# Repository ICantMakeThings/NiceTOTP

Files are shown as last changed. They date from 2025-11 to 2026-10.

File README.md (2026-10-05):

# NiceTOTP certification-mark-PL000020-wide

ew
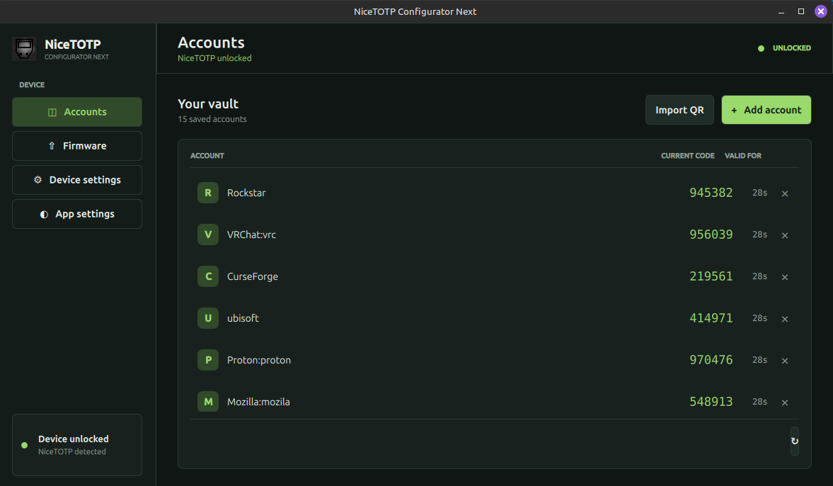
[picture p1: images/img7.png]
Repeat new PIN


## Wiki

- [What is NiceTOTP?](#what-is-nicetotp)
- [But Why?](#but-why)
- [Hardware](#hardware-is)
- [Usage](#usage)
	- [UI](Docs/ui.md)
- [Installation](#installation)
	- [Standard installation](#standard-installation)
	- [Protected installation](#protected-installation)
- [More Info](#more-info)
- [Build protected from source](Docs/build-protected-from-source.md)

# What is NiceTOTP?

Time-based one-time password (TOTP). aka: 2FA! 
A alternetive to [Authy](https://www.authy.com/) / [Google Authenticator](https://play.google.com/store/apps/details?id=com.google.android.apps.authenticator2). 

Full offline, Air Gapped. And Standalone once all Keys have been added.

TOTP keys and other FS are stored in an AES-256-GCM encrypted vault, with a key derived from the passcode using PBKDF2-HMAC-SHA-256. Vaults use a random starting IV followed by monotonically increasing IVs.

A four-digit passcode is still vulnerable to offline guessing if an attacker extracts the flash. Use a longer, unpredictable numeric passcode; a lengt of 13 can make a attacker wait up to 8 years on the most common GPU* 

[Video here](https://www.youtube.com/watch?v=sLiadPXk7rc)

## But Why?? 

There are a few reasons why I made this device, mainly to lose dependence of my phone. But not just, What if your phone breaks, bricks, or something else? I rather have lots of devices that don't depend on eachother rather than a all in one for that reason, plus most "universal" stuff performs worse than a specific device for that single function. As of right now, I'd say it's almost complete (enough to daily drive), possibly a few more hardware security features, maybe UI polishing, fixing any bugs i haven't found yet and should be perfect. The cost is ~£6 excluding 3D printing.

## Hardware is:
+ Nice!Nano: [AliExpress Link](https://s.click.aliexpress.com/e/_omlmCuu)
+ DS3231 RTC: [AliExpress Link](https://s.click.aliexpress.com/e/_omVV4ia)
+ 0.96Inch Display: [AliExpress Link](https://s.click.aliexpress.com/e/_ooXwYgq)
+ 6*6 Silicone Switch: [AliExpress Link](https://s.click.aliexpress.com/e/_oDcs8Wa)
+ 3D [model](https://www.thingiverse.com/thing:7087241)

*Note: These are referral links. If you purchase through it, I earn a commission at no extra cost to you.*

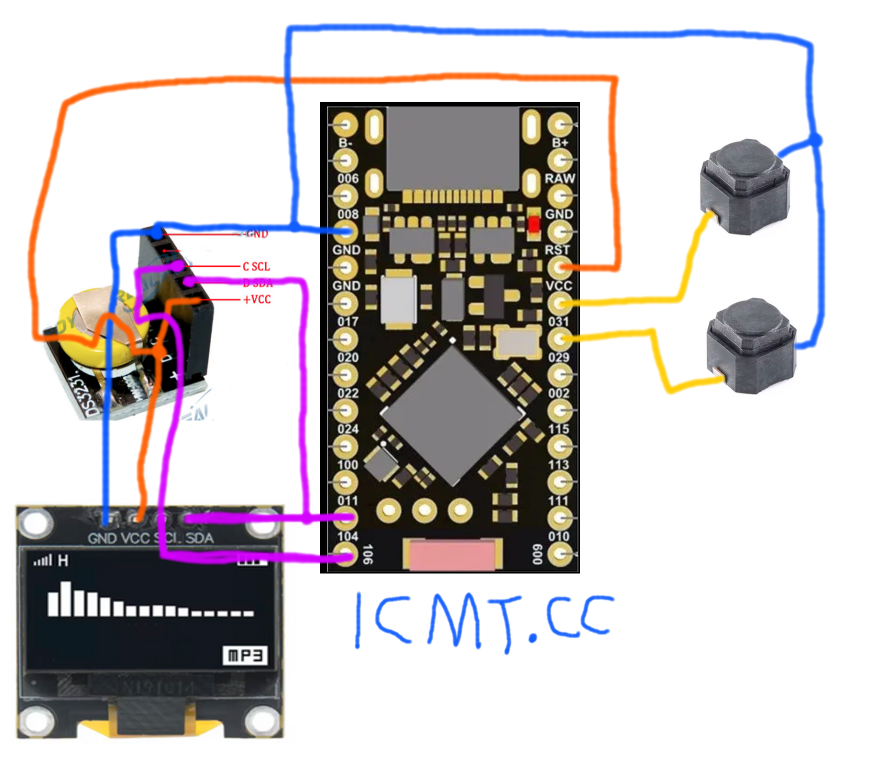
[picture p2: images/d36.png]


# Usage
#### Use the [NiceTOTP-ConfiguratorNext](https://github.com/ICantMakeThings/NiceTOTP/releases)  (Firmware update doesnt work rn*)
#### or you can use serial commands:
- `setunixtime` example: `setunixtime 1751925355` 
- The first `setunixtime` stores the real time for future auto-calibration which after 30 days it will compensate for any drift in the DS3231.
- `manualcalibration <offset>` example: `manualcalibration 3` sets the DS3231 aging register from -128 to 127 and locks automatic calibration
- `lockcalibration` stops auto-calibration
- `unlockcalibration` turns back on auto-calibration
- `getcalibration` reports the aging offset, baseline timestamp, and lock state
- `clearcalibration` clears the aging correction and removes the stored calibration baseline
- `add <username> <base32secret>` example: `add test JBSWY3DPEHPK3PXP` ([Compare](https://totp.danhersam.com/?secret=JBSWY3DPEHPK3PXP))
- `list`
- `del <GetTheIDFromListCommand>` example: `del 1`
- `factoryreset` (Power cycle after)

# Installation

### Standard installation

If you don't care about proper security*, download the [NiceTOTP-ConfiguratorNext](https://github.com/ICantMakeThings/NiceTOTP/releases) and use the unsigned `NiceTOTP-V1x.uf2` firmware.

**Or if you just want to test the device without commiting to the protected bootloader / hassle with setting it up or not owning a ST-Link*

+ Or Drag and drop the .UF2 onto the nicenano drive when doubble clicking reset (short rst pin with usbc sheild tapping twice quickly)

### Protected installation
- Download `Signed.zip` from latest release, and follow
[Protected installation](Docs/build-protected-from-source.md) (Also includes installing from source)

# More Info

+ In 2 months the RTC drifted 8s forward. (Now there is a calibration feature, so should be better, to be commented on further.)

+ Battery seems to last about 1 year with a 1000mAh Battery.

+ Make sure not to let it discharge as it will go in a soft brick, to unbrick you just press rst 

#### GPU* 

- The algorythm is **50,000 PBKDF2** and the number is the expected value which is ½ of the worse-case scenario.
- It is based on cracking it with a NVIDIA GeForce RTX 3060 as its the most common GPU based on [Steam Hardware & Software Survey: August 2026.](https://store.steampowered.com/hwsurvey/En)
- It is recommended to have a pin of at least 13 Charicters
- You can have a look on [this webiste](https://jmrp.io/tools/pin-brute-force-calculator/) to test around different hardware, make sure PBKDF2 iterations is set to `50000`

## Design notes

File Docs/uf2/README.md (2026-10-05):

# USB Flashing Format (UF2)

UF2 is a file format, developed by Microsoft for [PXT](https://github.com/Microsoft/pxt) 
(also known as [Microsoft MakeCode](https://makecode.com)), that is particularly suitable for 
flashing microcontrollers over MSC (Mass Storage Class; aka removable flash drive).

For a more friendly explanation, check out [this blog post](https://makecode.com/blog/one-chip-to-flash-them-all).
Also, take a look at the list of [implementations](#implementations) at the bottom of this document.

## Overview

The UF2 file consists of 512 byte blocks, each of which is self-contained and independent of others. 
Each 512 byte block consists of (see below for details):
* magic numbers at the beginning and at the end
* address where the data should be flashed
* up to 476 bytes of data

The data transfers over MSC always arrive in multiples of 512 bytes.
Together with the FAT file system structure, this means that blocks of the
UF2 file are always aligned with the MSC writes - the microcontroller 
never gets a partial file.

The magic numbers let the microcontroller distinguish an UF2 file block from
other data (eg., FAT table entry, or various book-keeping files stored by some
operating systems).  When a UF2 block is recognized, it can be flashed
immediately (unless flash page size is more than 256 bytes; in that case a buffer
is needed). The actual handling of file format during writing is very simple
(~10 lines of C code in simplest version).

## File format

A UF2 file consists of 512 byte blocks. Each block starts with a 32 byte
header, followed by data, and a final magic number.
All fields, except for data, are 32 bit unsigned little endian integers.

| Offset | Size | Value |
|---|---|---|
| 0 | 4 | First magic number, `0x0A324655` (`"UF2\n"`) |
| 4 | 4 | Second magic number, `0x9E5D5157` |
| 8 | 4 | Flags |
| 12 | 4 | Address in flash where the data should be written |
| 16 | 4 | Number of bytes used in data (often 256) |
| 20 | 4 | Sequential block number; starts at 0 |
| 24 | 4 | Total number of blocks in file |
| 28 | 4 | File size or board family ID or zero |
| 32 | 476  | Data, padded with zeros |
| 508 | 4 | Final magic number, `0x0AB16F30` |

The following C struct can be used:

```C
struct UF2_Block {
    // 32 byte header
    uint32_t magicStart0;
    uint32_t magicStart1;
    uint32_t flags;
    uint32_t targetAddr;
    uint32_t payloadSize;
    uint32_t blockNo;
    uint32_t numBlocks;
    uint32_t fileSize; // or familyID;
    uint8_t data[476];
    uint32_t magicEnd;
} UF2_Block;
```

### Flags

Currently, there are five flags defined:

* `0x00000001` - **not main flash** - this block should be skipped when writing the
  device flash; it can be used to store "comments" in the file, typically
  embedded source code or debug info that does not fit on the device flash
* `0x00001000` - **file container** - see below
* `0x00002000` - **familyID present** - when set, the `fileSize/familyID` holds a value
  identifying the board family (usually corresponds to an MCU)
* `0x00004000` - **MD5 checksum present** - see below
* `0x00008000` - **extension tags present** - see below

### Family ID

This field is optional, and should be set only when the corresponding
flag is set. It is recommended that new bootloaders require the field to
be set appropriately, and refuse to flash UF2 files without it.
If you're developing your own bootloader, and your
board family isn't listed here, pick a new family ID at random. It's good
to also send a PR here, so your family can be listed.

If the `familyID` doesn't match, the bootloader should disregard the
entire block, including `blockNo` and `numBlocks` fields.
In particular, writing a full UF2 file with non-matching `familyID`
should not reset the board.
This also allows for several files with different `familyID` to be
simply concatenated together, and the whole resulting file to be copied
to the device with only one actually being written to flash.

#### Picking numbers at random

The reason to pick numbers at random is to minimize risk of collisions
in the wild. Do not pick random numbers by banging on keyboard, or by using
`0xdeadf00d`, `0x42424242` etc. A good way is to use the following
shell command: `printf "0x%04x%04x\n" $RANDOM $RANDOM`
Another good way is the link at the bottom of https://microsoft.github.io/uf2/patcher/
This procedure was unfortunately not used for the SAMD51 and NRF52840 below.

#### Family list

The current master list of family IDs is maintained in a [JSON file](../../uf2/utils/uf2families.json).

### Rationale

The magic number at the end is meant to mitigate partial block writes.

Second and final magic numbers were randomly selected, except for the last byte
of final magic number, which was forced to be `'\n'` (`0xA`). Together with the
first magic number being `"UF2\n"` this makes it easy to identify UF2 blocks in
a text editor.

The header is padded to 32 bytes, as hex editors commonly use 16 or 32 bytes
as line length.  This way, the data payload is aligned to line start.

32 bit integers are used for all fields so that large flash sizes can be
supported in future, as well as for simplicity. Little endian is used, as most
microcontrollers are little endian. 8 bit microcontrollers can choose to just
use the first 16 bits of various header fields.

The total number of blocks in the file and the sequential block number make it
easy for the bootloader to detect that all blocks have been transferred. It
requires one bit of memory per block (eg., on SAMD21G18A it's 128 bytes).
Alternatively, the bootloader might ignore that and just implement a reset
after say 1 second break in incoming UF2 blocks.

### Payload sizes

The number of data bytes is configurable and depends on the size of
the flash page (that is the smallest size that can be erased) on the
microcontroller.

* if the page size is more than `476` bytes, the bootloader should support
  any payload size, as it needs to buffer the entire page in memory anyway
* if the page size is less than `476` bytes, the payload should be a multiple
  of page size, so it can be written without buffering; the target address
  should also be a multiple of page size

In any event, payload size and target address should always be 4-byte aligned.

Note that payload size of `256` is always correct, and makes it easy to convert
between flash addresses and UF2 file offsets.

For example, on Atmel's SAMD21 chips the page size is `256` bytes, and this 
also is the payload size. If the page size was `128` bytes, one could use
payload of `128*3`. Nordic nRF51 has page size of `1024` bytes, and thus 
any payload size should be allowed.

### Embedding sources

Some IDEs will embed program sources in the UF2 file. This allows a UF2 files to be
loaded by the IDE and serve as a natural backup and transfer format.
This can be done in two ways:

* using the "not main flash" flag
* using normal blocks that are flashed to the device

If the bootloader can expose `CURRENT.UF2` file (see below) and there is enough
flash available, than the second option is more desirable, as it allows sharing
programs directly from the board.

See https://makecode.com/source-embedding for more info.

### Robustness

The file format is designed specifically to deal with the following problems:

* operating system (OS) writing blocks in different order than occurs in a file
* OS writing blocks multiple times
* OS writing data that is not UF2 blocks
* OS writing first/final part of a block, possibly for metadata detection or search indexing

The only file system assumption we make is that blocks of file are aligned with
blocks on the hard drive. It's likely true of many file systems besides FAT.

We also assume that USB MSC device reports its block size to be a multiple of `512`
bytes. In the wild these devices always almost report exactly `512`, and some
operating systems do not support other values.

## Files exposed by bootloaders

Bootloaders may expose virtual files in their MSC devices.  These are
standardized here, so that flashing tools can automatically detect the
bootloaders.

* `INFO_UF2.TXT` - contains information about the bootloader build and the board on which it is running
* `INDEX.HTM` - redirects to a page that contains an IDE or other information
* `CURRENT.UF2` - the contents of the entire flash of the device, starting at `0x00000000`, with `256` payload size;
  thus, the size of this file will report as twice the size of flash

Flashing tools can use the presence of `INFO_UF2.TXT` (in upper or lower case,
as FAT is case-insensitive) file as an indication that a given directory is
actually a connected UF2 board. The other files should not be used for
detection.

Typical `INFO_UF2.TXT` file looks like this:
```
UF2 Bootloader v1.1.3 SFA
Model: Arduino Zero
Board-ID: SAMD21G18A-Zero-v0
```

The `Board-ID` field is machine-readable and consists of a number of dash-separated tokens.
The first token is the CPU type, second is the board type, and third is the board revision.
More tokens can be also added.

The bootloader should contain its info file as a static string somewhere in its code.
If possible, the last word of the bootloader code should point to this string.
This way, the info file can be found in the initial section of the `CURRENT.UF2`
file as well. Thus, a board type can be determined from the contents of `CURRENT.UF2`.
This is particularly useful with the source embedding (see above).

## File containers

It is also possible to use the UF2 format as a container for one or more
regular files (akin to a TAR file, or ZIP archive without compression).  This
is useful when the embedded device being flashed sports a file system.

The program to run may reside in one of the files, or in the main flash memory.

In such a usage the `file container` flag is set on blocks, the field `fileSize`
holds the file size of the current file, and the field `targetAddr` holds the
offset in current file.

The `not main flash` flag on blocks should be ignored when the `file container` is set.

The file name is stored at `&data[payloadSize]` (ie., right after the actual payload) and
terminated with a `0x00` byte.  The format of filename is dependent on the
bootloader (usually implemented as some sort of file system daemon). 

The bootloader will usually allow any size of the payload.

The current files on device might be exposed as multiple UF2 files, instead of
a single `CURRENT.UF2`. They may reside in directories, however, due to UF2 general
design, it doesn't matter which directory the UF2 file is written to.

Typical writing procedure is as follows:
* validate UF2 magic numbers
* make sure that `targetAddr < fileSize` and that `fileSize` isn't out of reasonable range
* write `0x00` at `data[475]` to ensure NUL termination of file name
* read file name from `&data[payloadSize]`; perform any mapping on the file name
* create a directory where the file is to be written if it doesn't exist
* open the file for writing
* truncate the file to `fileSize`
* seek `targetAddr`
* write the payload (ie., `data[0 ... payloadSize - 1]`)
* close the file

The fields `blockNo` and `numBlocks` refer to the entire UF2 file, not the current
file.

## MD5 checksum

When the `0x4000` flag is set, the last 24 bytes of `data[]` hold the following structure:

| Offset | Size | Value |
|---|---|---|
| 0 | 4 | Start address of region |
| 4 | 4 | Length of region in bytes |
| 8 | 16 | MD5 checksum in binary format |

The flashing program should compute the MD5 sum of the specified region.
If the region checksum matches, flashing of the current block can be skipped.
Typically, many blocks in sequence will have the same region specified,
and can all be skipped, if the matching succeeded.
The position of the current block will typically be inside of the region.
The position and size of the region should be multiple of page erase size
(4k or 64k on typical SPI flash).

This is currently only used on ESP32, which is also why MD5 checksum is used.

## Extension tags

When the `0x8000` flag is set, additional information can be appended right after
payload data (i.e., it starts at `32 + payloadSize`).
Every tag starts at 4 byte boundary.
The first byte of tag contains its total size in bytes (including the size byte
and type designation).
The next three bytes designate the type of tag (if you want to define custom
tags, pick them at random).
The last tag has size of `0` and type of `0`.

Standard tag designations follow:
* `0x9fc7bc` - version of firmware file - UTF8 semver string
* `0x650d9d` - description of device for which the firmware file is destined (UTF8)
* `0x0be9f7` - page size of target device (32 bit unsigned number)
* `0xb46db0` - SHA-2 checksum of firmware (can be of various size)
* `0xc8a729` - device type identifier - a refinement of `familyID` meant to identify a kind of device
  (eg., a toaster with specific pinout and heating unit), not only MCU; 32 or 64 bit number; can be hash of `0x650d9d`

For example, the following bytes encode firmware version `0.1.2` for device
named `ACME Toaster mk3` (line breaks added for clarity):

```
09 bc c7 9f 30 2e 31 2e 32 00 00 00
14 9d 0d 65 41 43 4d 45 20 54 6f 61 73 74 65 72 20 6d 6b 33
00 00 00 00
```

Extension tags can, but don't have to, be repeated in all blocks.

## Implementations

### Bootloaders

* [Microchip ATSAMD21 and ATSAMD51](https://github.com/Microsoft/uf2-samdx1)
* [Arduino UNO](https://github.com/mmoskal/uf2-uno)
* [STM32F103](https://github.com/mmoskal/uf2-stm32)
* [STM32F4](https://github.com/mmoskal/uf2-stm32f)
* [Nordic NRF52840](https://github.com/adafruit/Adafruit_nRF52840_Bootloader)
* [Linux (RPi Zero)](https://github.com/microsoft/uf2-linux)
* [Cypress FX2](https://github.com/whitequark/libfx2/tree/master/firmware/boot-uf2)
* [Tiny UF2](https://github.com/adafruit/tinyuf2) - Support ESP32-S2, iMXRT10xx, STM32F4
* [RP2040 chip](https://www.raspberrypi.org/products/raspberry-pi-pico/) - native support in silicon
* [UF2-ChibiOS](https://github.com/striso/uf2-ChibiOS) - Supports STM32H7

There's an ongoing effort to implement UF2 in [Codal](https://github.com/lancaster-university/codal-core).

### Editors

* https://arcade.makecode.com
* https://makecode.adafruit.com
* https://makecode.seeedstudio.com
* https://maker.makecode.com

### Libraries

* https://www.npmjs.com/package/uf2

## License

MIT

## Code of Conduct

This project has adopted the [Microsoft Open Source Code of Conduct](https://opensource.microsoft.com/codeofconduct/). For more information see the [Code of Conduct FAQ](https://opensource.microsoft.com/codeofconduct/faq/) or contact [opencode@microsoft.com](mailto:opencode@microsoft.com) with any additional questions or comments.

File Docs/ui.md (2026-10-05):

# **UI Usage**

Whole device

## **Controls**

| Action | Function |
| --- | --- |
| Press **Left** | Move up / decrease / wake device |
| Press **Right** | Move down / increase / wake device |
| Hold **Left** or **Right** | Add / confirm current pin number |
| Hold **Left + Right** | Select / confirm menu setting |
| Tap both **Left + Right** | Delete the last digit when entering a PIN |

---

## **Unlocking the Device**

When the device is locked, the display shows the PIN screen.

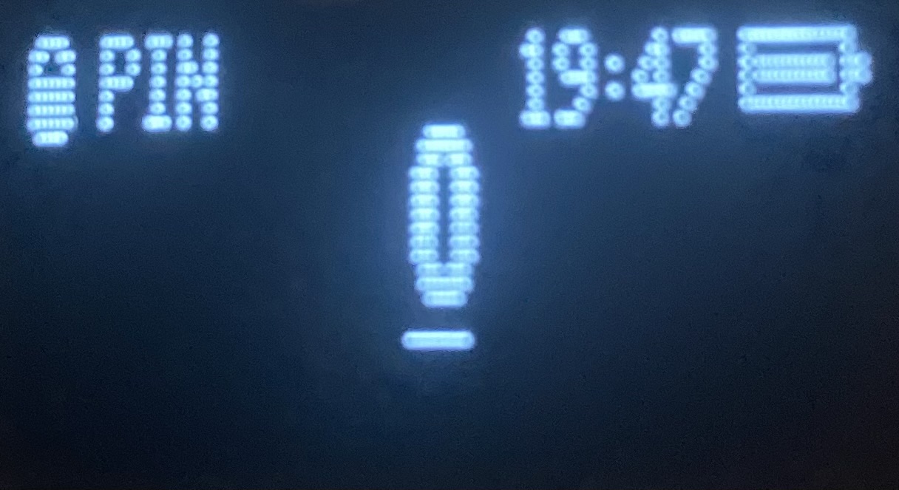
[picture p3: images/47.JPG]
Login PIN screen


### **Entering a PIN**

1. Press **Left/Right** to change the digit.
2. Hold **Left** or **Right** to add the digit.
3. Repeat until the PIN is entered.
4. Hold **Left + Right** to submit the PIN.

5. If you make a mistake, Press **Left + Right** to remove the last entered digit.

*Note: Pin verification takes about **17 seconds**.*

---

## **TOTP Code**

After unlocking, the main screen displays the current TOTP code.

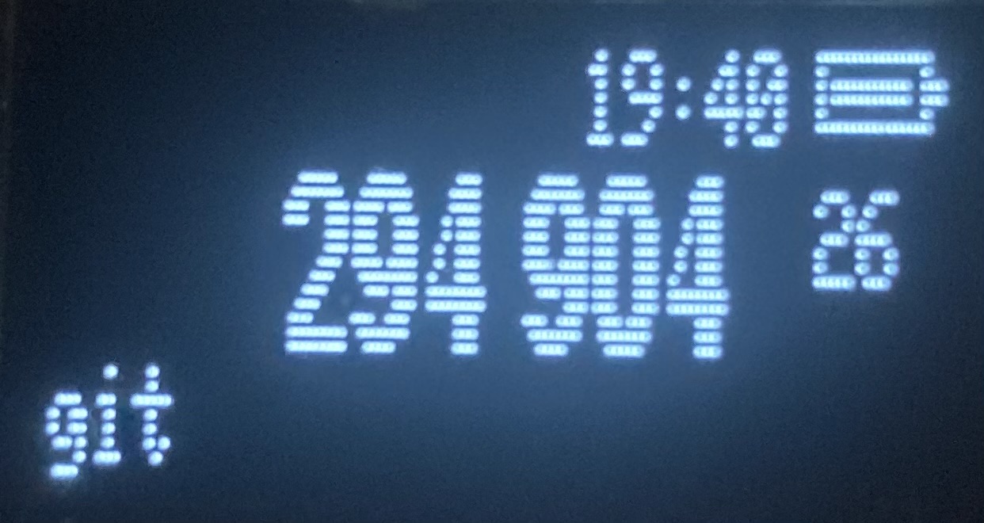
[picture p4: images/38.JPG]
Main TOTP screen


* **Left** - previous account
* **Right** - next account
* The number on the right shows the remaining seconds for the current TOTP code.

NiceTOTP automatically goes to sleep after **60 seconds of inactivity**.

---

## **Settings Menu**

From the main TOTP screen, **hold Left + Right** to open the settings menu.

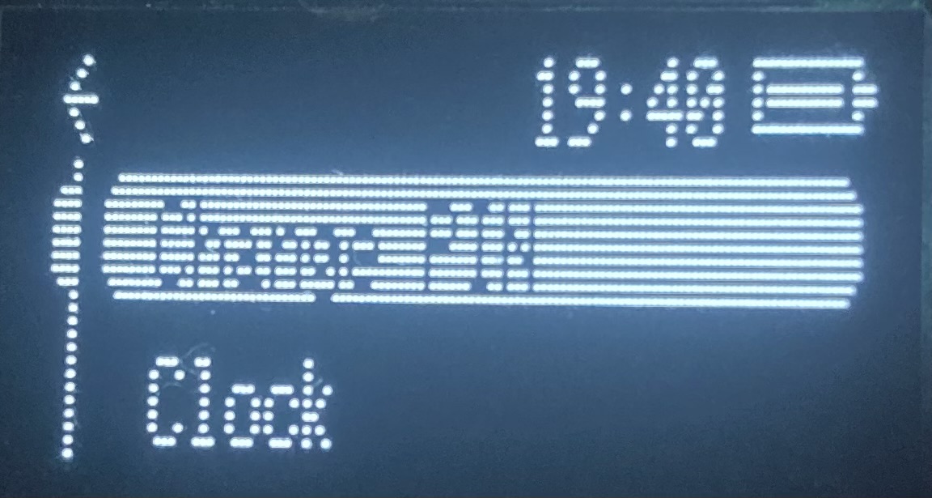
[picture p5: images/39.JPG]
Settings menu


The menu as of [V14](https://github.com/ICantMakeThings/NiceTOTP/releases/tag/NiceTOTP-V014) contains:

* **Change PIN**
* **Clock**
* **Sleep**

Use **Left/Right** to move through the menu and **hold Left + Right** to select submenu.

The selected item is inverted.

---

## **Clock Settings**

Select **Clock** from the settings menu.

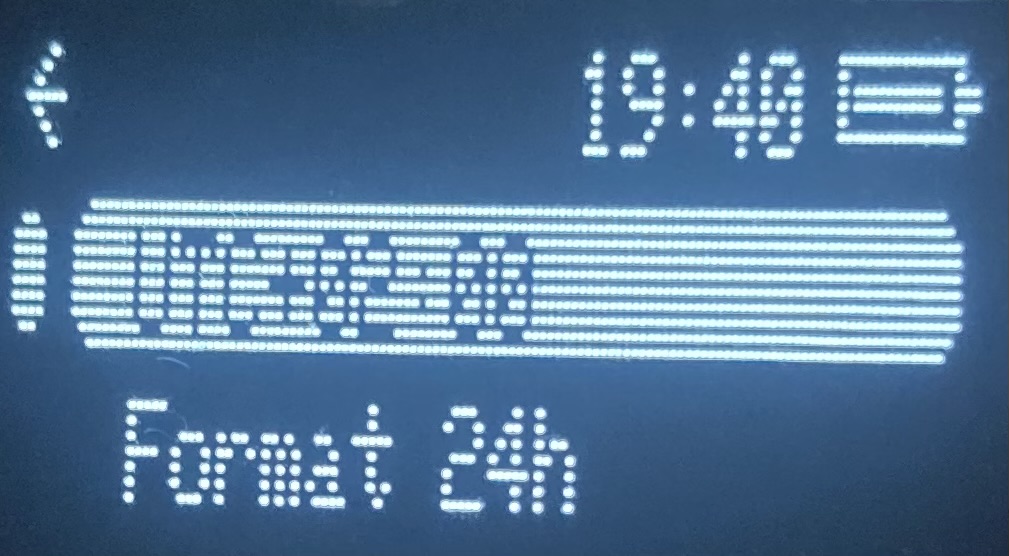
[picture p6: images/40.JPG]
Clock settings


The clock settings allow you to change:

* **UTC offset** - in 30 minuite steps
* **Time format** - 24-hour or 12-hour
* **Back**

Hold **Left + Right** to save the setting.

---

## **Changing the PIN**

Select **Change PIN** from the settings menu.

### **1. Verify current PIN**

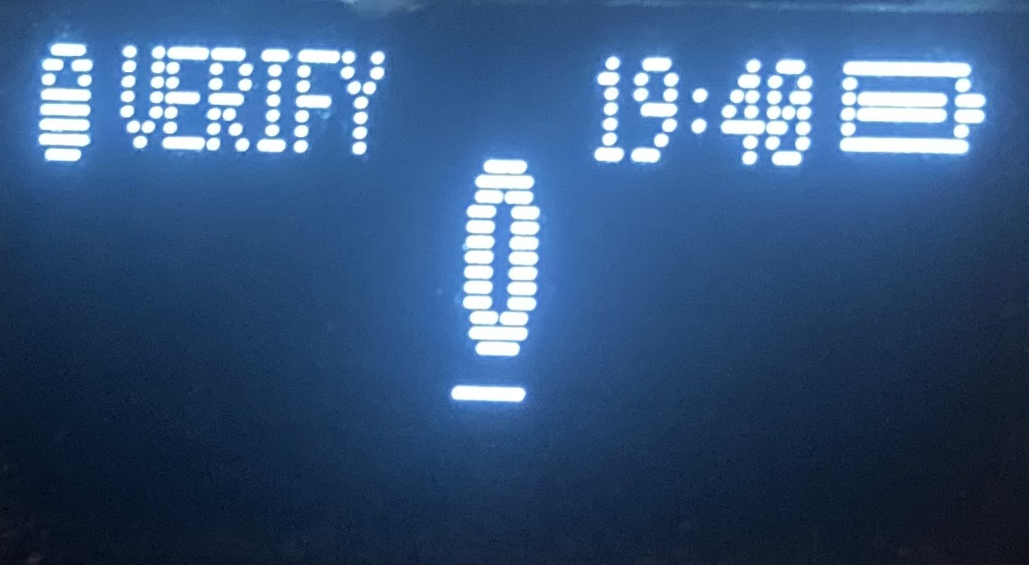
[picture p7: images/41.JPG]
Verify current PIN


- Enter your current PIN.

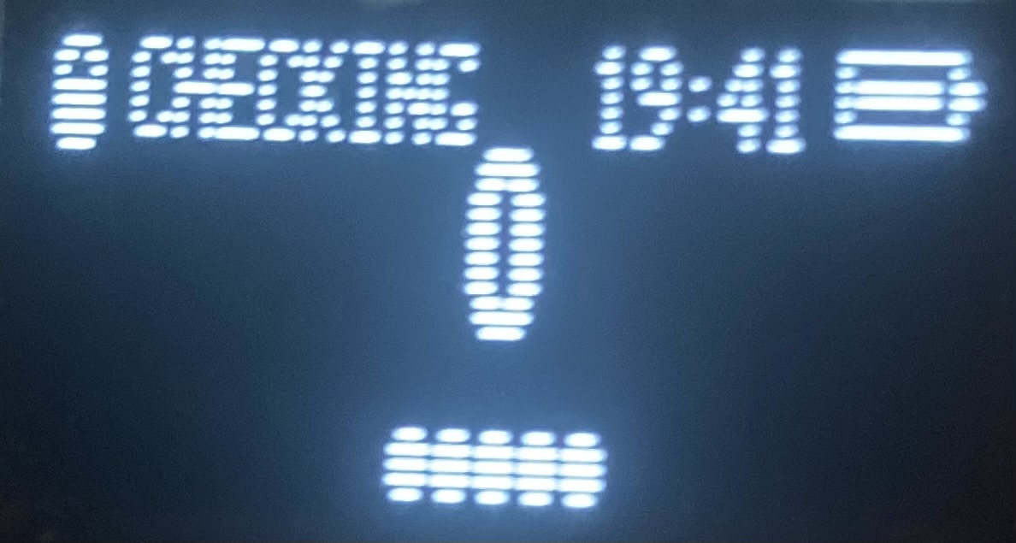
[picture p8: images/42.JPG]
Checking PIN


### **2. Enter the new PIN**

After the current PIN is verified, enter your new PIN.

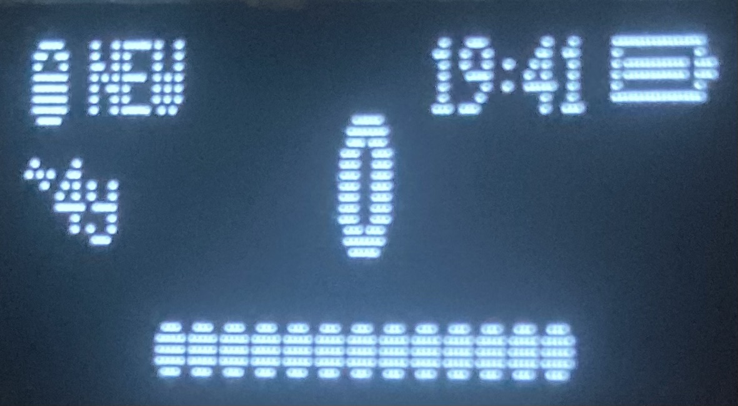
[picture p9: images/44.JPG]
New PIN


- The display shows the estimated brute-force time as the PIN gets longer.

- The algorythm is **50,000 PBKDF2** and the number is the expected value which is ½ of the worse-case scenario.
- It is based on cracking it with a NVIDIA GeForce RTX 3060 as its the most common GPU based on [Steam Hardware & Software Survey: August 2026.](https://store.steampowered.com/hwsurvey/En)
- It is recommended to have a pin of at least 13 Charicters
- You can have a look on [this webiste](https://jmrp.io/tools/pin-brute-force-calculator/) to test around different hardware, make sure PBKDF2 iterations is set to `50000`
- TOTP keys and other FS are stored in an AES-256-GCM authenticated encrypted vault, with a key derived from the passcode using PBKDF2-HMAC-SHA-256. Vaults use a random starting IV followed by monotonically increasing IVs.

A PIN must be between **4 and 20 characters**.

### **3. Confirm the new PIN**

Enter the same PIN again.

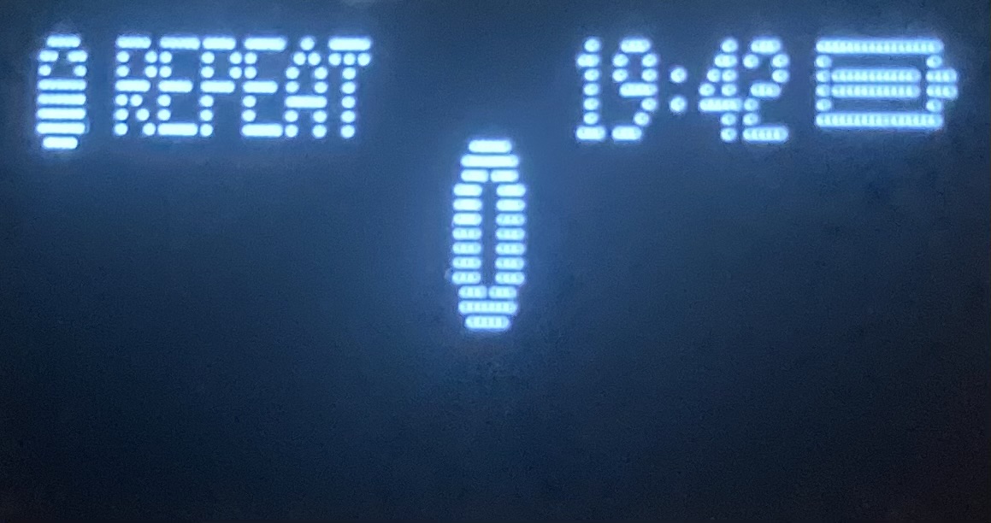
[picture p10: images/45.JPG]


If both PIN entries match, the new PIN is saved.

---

# **App UI**

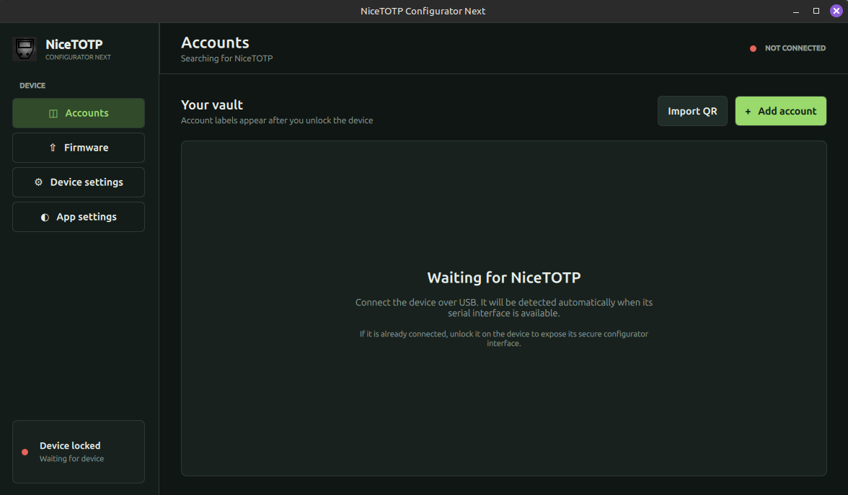
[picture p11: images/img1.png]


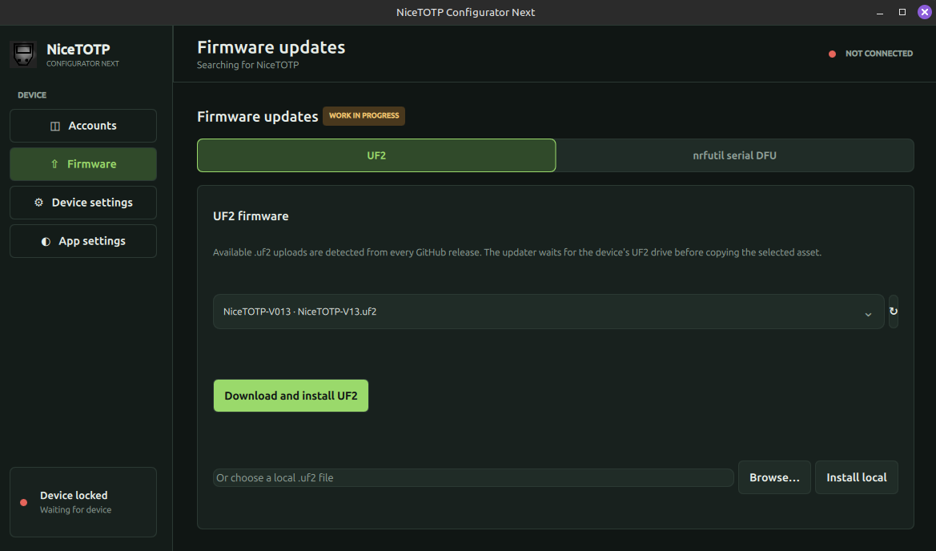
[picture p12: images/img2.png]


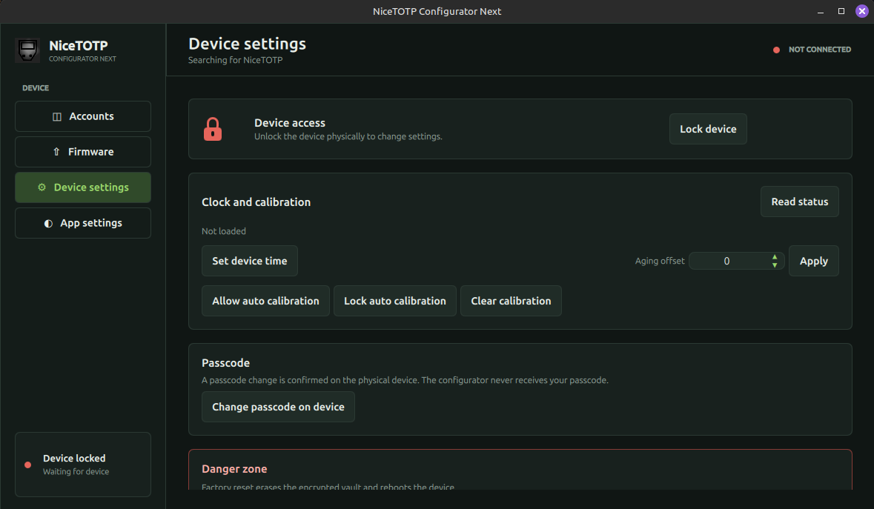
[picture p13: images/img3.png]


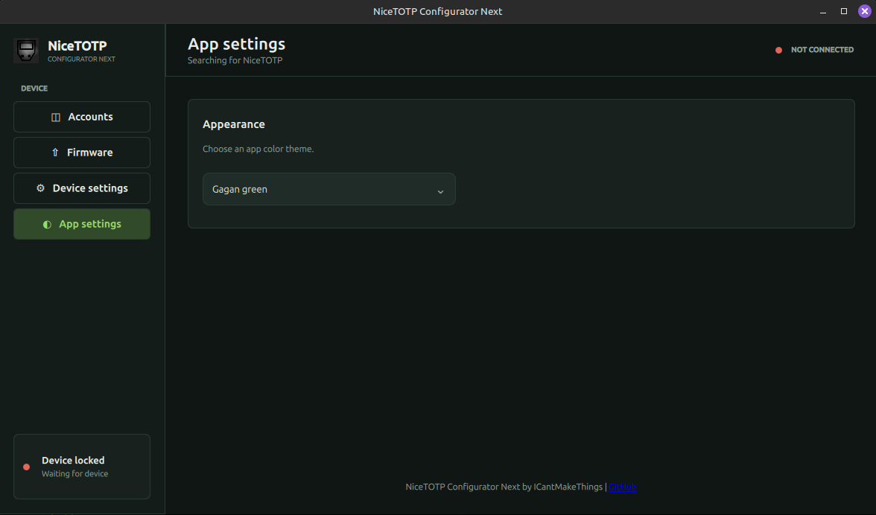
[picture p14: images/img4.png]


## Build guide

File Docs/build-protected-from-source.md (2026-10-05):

# Build Signed from source

*Note: Thease are Linux specific instructions. On Windows, use WSL 2*

**Note 2: Only follow this if you can keep private key SAFE, It's more recommened to use Pre-Signed FW if you dont fully know what your doing.**

****

This guide builds the signed Bootloader and Firmware from source.

The bootloader is signed. **Keep `private.pem` private and backed up;** do not commit or share it. **Losing it means you cannot update the device.**

## 1. Get the source and tools

Get prerequisites:

Install: Git, Python 3, CMake, Make, the ARM GNU toolchain (`arm-none-eabi-gcc`), PlatformIO Core, Nordic nRF Command Line Tools (`nrfjprog`), and SEGGER J-Link. Add nice!nano support to PlatformIO using [this guide](https://github.com/ICantMakeThings/Nicenano-NRF52-Supermini-PlatformIO-Support).

Clone this repository:

```sh
git clone https://github.com/ICantMakeThings/NiceTOTP.git
```

open its root directory:
```sh
cd NiceTOTP
```

## 2. Create the signing key

Run this **once**:

```sh
./Scrypts/setup-nrfutil.sh
```

This creates `~/nrfutil-venv` and `private.pem` **(WHICH YOU DO NOT SHARE, KEEP SAFE, YOU WILL NEED FOR FUTURE FW UPDATES)** if they do not already exist. The key is local to this checkout by default. Back it up securely, and use the same key for the bootloader and firmware.

## 3. Build and flash the signed bootloader

Build the bootloader:

```sh
./Scrypts/build-signed-bootloader.sh
```

The script clones Adafruit's bootloader source into ignored `build/` and builds it with the public key corresponding to `private.pem`. 

It does not flash the device yet. You need a J-Link debugger like ST-LINK, flash the SoftDevice and bootloader from the repository root:

```sh
cmake --build build/nice_nano-signed-bootloader --target flash-all
```

This target uses `nrfjprog` to program and verify the files. Do not run APPROTECT-enabled firmware until the signed bootloader is verified.

## 4. Build and install signed firmware

For the initial firmware flash, keep `enableApprotect();` commented out, and leave both related lines:
```ini
;extra_scripts = post:Scrypts/approtect.py
;build_flags = -DAPPROTECT_ENABLED=1
```
commented out in `platformio.ini`. 

Build the firmware:

```sh
pio run
```

With the board still connected over SWD, flash the firmware:

```sh
nrfjprog --program .pio/build/nicenano/firmware.hex --verify --sectorerase -f nrf52 --reset
```

## 5. Enable APPROTECT and install signed firmware

After verifying that the firmware BOOTs, enable protection for the final firmware by uncommenting:

1. `enableApprotect();` in `setup()` in `src/main.cpp`
 
2. `extra_scripts = post:Scrypts/approtect.py` and `build_flags = -DAPPROTECT_ENABLED=1` in `platformio.ini`, it will look like:

```ini
extra_scripts = post:Scrypts/approtect.py
build_flags = -DAPPROTECT_ENABLED=1
```

Build and upload the final signed firmware over **USB** DFU:

```sh
pio run
pio run -t upload --upload-port /dev/ttyACM0
```

Replace `/dev/ttyACM0` with the device's serial port. 

The upload script signs the firmware with the local key and uses `adafruit-nrfutil`. APPROTECT takes effect on the first boot of this final firmware; later uploads must use the signed DFU path. The signed bootloader does not support UF2 drag-and-drop.

## 6. Build the configurator

Install Python 3 and the app's dependencies, then package the Qt Quick configurator with PyInstaller:

```sh
python -m pip install -r Scrypts/requirements.txt
pyinstaller --noconfirm Scrypts/NiceTOTP-Configurator.spec
```

The packaged application is written to `dist/`. QR image import uses ZBar; install its shared library before running the app:

```sh
sudo apt-get install libzbar0
```

On macOS, install ZBar with `brew install zbar`. On Windows, use the Python packages above in a Windows Python environment.

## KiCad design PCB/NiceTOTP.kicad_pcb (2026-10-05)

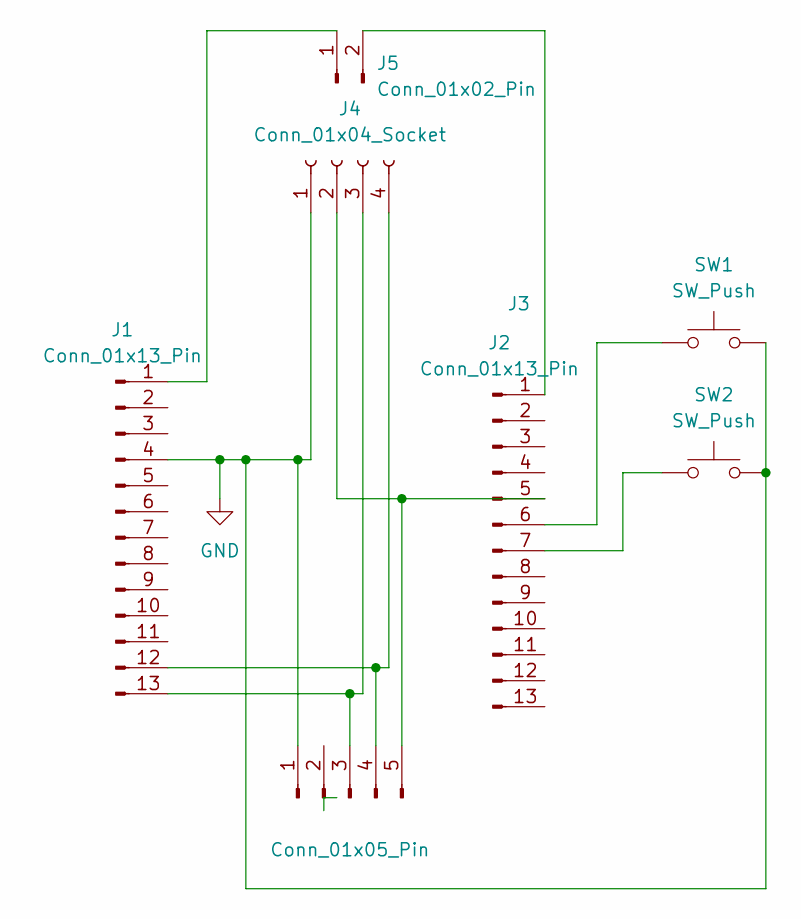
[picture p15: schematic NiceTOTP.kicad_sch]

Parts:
J1, J2: Conn_01x13_Pin; PinHeader_1x13_P2.54mm_Vertical
J3: Conn_01x05_Pin; PinHeader_1x05_P2.54mm_Vertical
J4: Conn_01x04_Socket; PinHeader_1x04_P2.54mm_Vertical
J5: Conn_01x02_Pin; PinHeader_1x02_P2.54mm_Vertical
SW1, SW2: SW_Push; SW_Push_1TS009xxxx-xxxx-xxxx_6x6x5mm

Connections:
GND: J1.4, J3.1, J4.1, SW1.2, SW2.2
unnamed: J1.1, J5.1
unnamed: J1.12, J3.4, J4.4
unnamed: J1.13, J3.3, J4.3
unnamed: J2.1, J5.2
unnamed: J2.5, J3.5, J4.2
unnamed: J2.6, SW1.1
unnamed: J2.7, SW2.1

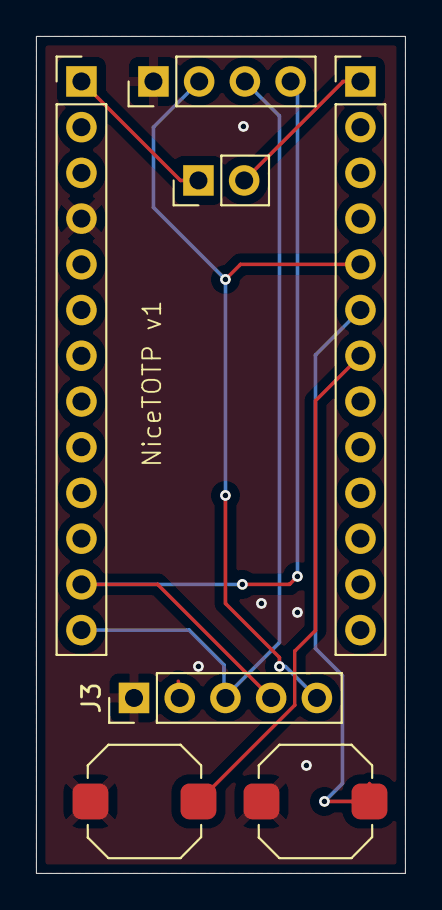
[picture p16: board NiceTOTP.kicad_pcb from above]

Board: 2 copper layers, 20.5 x 46.5 mm, 7 parts (0 on the bottom side), 8 nets.

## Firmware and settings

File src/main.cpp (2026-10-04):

// Hello! This is a nRF52840 based TOTP with a SSD... something display.
// Has a pin to lock your stuff, and more soon
//
// commands include:
// setunixtime
// manualcalibration <aging offset>
// clearcalibration
// add <username> <base32secret>
// factoryreset (power cycle the device)
// list
// del <GetTheIDFromListCommand>
// clear
// pinsetup
// lock
// NEW << A app to configure
#include <Arduino.h>
#include <Wire.h>
#include <RTClib.h>
#include <Adafruit_SSD1306.h>
#include <Adafruit_LittleFS.h>
#include <InternalFileSystem.h>
#include <SPI.h>
#include "TOTP++.h"
#include <Fonts/FreeSansBold9pt7b.h>
#include <nrf.h>
#include <nrf_gpio.h>
#include <bluefruit.h>
#include <Adafruit_TinyUSB.h>
#include <Adafruit_nRFCrypto.h>
#include <AES.h>
#include <GCM.h>
#include <SHA256.h>
#include <hal/nrf_power.h>
#include "nrf_nvic.h"

// Constants

#define DFU_MAGIC_UF2_RESET 0x57
using namespace Adafruit_LittleFS_Namespace;

BLEUart bleuart;
BLEDis bledis;

RTC_DS3231 rtc;

const uint8_t lockIcon8x8[] PROGMEM = {
    0b00111100, 0b01100110, 0b01000010, 0b01111110,
    0b01111110, 0b01111110, 0b01111110, 0b00111100};

#define SCREEN_WIDTH 128
#define SCREEN_HEIGHT 32
#define OLED_RESET -1
Adafruit_SSD1306 display(SCREEN_WIDTH, SCREEN_HEIGHT, &Wire, OLED_RESET);

#define BUTTON_UP_PIN PIN_029
#define BUTTON_DOWN_PIN PIN_031

const unsigned long INACTIVITY_TIMEOUT = 60000;
const unsigned long CONFIGURATOR_TIMEOUT = 5000;
const int MAX_PIN_LENGTH = 20;
const int MIN_PIN_LENGTH = 4;
const int MAX_KEYS = 50;
const int MAX_FAILED_ATTEMPTS = 10;
const uint32_t PBKDF2_ITERATIONS = 50000;
const char *PIN_SEARCH_ESTIMATES[17] = {
    "~128ms", "~1.3s", "~12.8s", "~2m", "~21m", "~4h", "~1d", "~15d", "~148d",
    "~4y", "~41y", "~406y", "~4.1ky", "~40.6ky", "~406ky", "~4.1My", "~40.6My"};
const uint32_t BUTTON_HOLD_NEXT_MS = 350;
const uint32_t BUTTON_HOLD_SELECT_MS = 400;
const uint32_t MENU_HOLD_MS = 400;

const char *PIN_FILENAME = "/pin.dat";
const char *KEYS_FILENAME = "/keys.dat";
const char *VAULT_FILENAME = "/vault.dat";
const char *ATTEMPTS_FILENAME = "/attempts.dat";
const char *CLOCK_DISPLAY_FILENAME = "/clock.cfg";
const char *CALIBRATION_FILENAME = "/calibration.dat";
const uint32_t CALIBRATION_INTERVAL = 30UL * 24UL * 60UL * 60UL;
const uint8_t DS3231_ADDRESS = 0x68;
const uint8_t DS3231_AGING_REGISTER = 0x10;

uint8_t failedAttempts = 0;
uint32_t lockoutUntilMillis = 0;
uint32_t lockoutDurationMillis = 0;
bool lockoutActive = false;

unsigned long lastActivityTime = 0;
unsigned long lastConfiguratorHeartbeat = 0;

char passcodeInput[MAX_PIN_LENGTH + 1] = {0};
uint8_t inputIndex = 0;
uint8_t selectedDigit = 0;
char pendingPasscode[MAX_PIN_LENGTH + 1] = {0};
uint8_t pendingPasscodeLength = 0;
char legacyPasscode[MAX_PIN_LENGTH + 1] = {0};
bool legacyMode = false;
bool legacyDataLoaded = false;

bool locked = true;
bool inPinSetup = false;
bool confirmingPasscode = false;
bool setupMismatch = false;
bool changingPasscode = false;
bool verifyingCurrentPasscode = false;
bool hashingPasscode = false;
bool hardwareCryptoReady = false;
uint32_t setupMessageUntil = 0;
bool menuActive = false;
uint8_t menuSelection = 0;
bool clockSettingsActive = false;
uint8_t clockSettingsSelection = 0;
bool editingClockOffset = false;
uint32_t wrongPinFlashStart = 0;
bool wrongPinFlashActive = false;
bool vaultPresent = false;
bool vaultUnlocked = false;
bool storageKeyReady = false;
uint8_t vaultSalt[16] = {0};
uint8_t storageKey[32] = {0};
uint8_t vaultFormatVersion = 3;
bool allowNonceInitialization = false;
uint32_t originalSetTime = 0;
int8_t agingOffset = 0;
bool calibrationLocked = false;
int16_t utcOffsetMinutes = 0;
bool clock24Hour = true;
uint32_t clockTextUpdatedAt = 0;
bool clockTextReady = false;
char cachedClockText[8] = {0};

struct KeyEntry
{
  char username[32];
  char base32secret[128];
};

KeyEntry keys[MAX_KEYS];
int keysCount = 0;
const size_t VAULT_CALIBRATION_OFFSET = 1 + MAX_KEYS * sizeof(KeyEntry);
const size_t VAULT_CLOCK_SETTINGS_OFFSET = VAULT_CALIBRATION_OFFSET + sizeof(uint32_t) + sizeof(int8_t) + 1;
const size_t VAULT_V2_PAYLOAD_SIZE = VAULT_CLOCK_SETTINGS_OFFSET;
uint8_t vaultPayload[VAULT_V2_PAYLOAD_SIZE + sizeof(utcOffsetMinutes) + 1] = {0};
bool saveKeys();
bool vaultFileIsComplete(const char *path);
bool saveClockDisplaySettings();
void loadClockDisplaySettings();

int selectedKeyIndex = 0;

TOTP totp;

void secureZero(void *memory, size_t length)
{
  volatile uint8_t *bytes = (volatile uint8_t *)memory;
  while (length-- > 0)
    *bytes++ = 0;
}

bool usbExposed = false;
bool usbExposureInitialized = false;

void setUSBExposure(bool exposed)
{
  if (usbExposureInitialized && exposed == usbExposed)
    return;

  if (exposed)
  {
    TinyUSBDevice.attach();
    delay(50);
  }
  else
  {
    TinyUSBDevice.detach();
    delay(50);
  }

  usbExposed = exposed;
  usbExposureInitialized = true;
}

void secureClearString(String &value)
{
  for (unsigned int i = 0; i < value.length(); i++)
    value.setCharAt(i, '\0');
  value = "";
}

bool fillCryptoRandom(uint8_t *output, size_t length)
{
  NRF_RNG->CONFIG = RNG_CONFIG_DERCEN_Enabled;
  NRF_RNG->TASKS_START = 1;
  for (size_t i = 0; i < length; i++)
  {
    NRF_RNG->EVENTS_VALRDY = 0;
    uint32_t timeout = 1000000;
    while (!NRF_RNG->EVENTS_VALRDY && timeout > 0)
      timeout--;
    if (timeout == 0)
    {
      NRF_RNG->TASKS_STOP = 1;
      secureZero(output, i);
      return false;
    }
    output[i] = (uint8_t)NRF_RNG->VALUE;
  }
  NRF_RNG->TASKS_STOP = 1;
  return true;
}

bool computeHmacSha256(const uint8_t *key, size_t keyLength, const uint8_t *data,
                       size_t dataLength, uint8_t output[32])
{
  if (hardwareCryptoReady)
  {
    nRFCrypto_Hmac hmac;
    uint32_t digest[16] = {0};
    bool okay = hmac.begin(CRYS_HASH_SHA256_mode, (uint8_t *)key, (uint16_t)keyLength) &&
                hmac.update((uint8_t *)data, dataLength) && hmac.end(digest) == 32;
    if (okay)
    {
      memcpy(output, digest, 32);
      secureZero(digest, sizeof(digest));
      return true;
    }
    secureZero(digest, sizeof(digest));
  }

  SHA256 hash;
  hash.resetHMAC(key, keyLength);
  hash.update(data, dataLength);
  hash.finalizeHMAC(key, keyLength, output, 32);
  hash.clear();
  return true;
}

void displayCode();

bool deriveVaultKey(const uint8_t *passcode, size_t passcodeLength, const uint8_t salt[16], uint8_t output[32])
{
  if (passcodeLength < MIN_PIN_LENGTH || passcodeLength > MAX_PIN_LENGTH)
    return false;

  uint8_t block[20];
  uint8_t u[32];
  uint8_t result[32];
  memcpy(block, salt, 16);
  block[16] = 0;
  block[17] = 0;
  block[18] = 0;
  block[19] = 1;

  if (!computeHmacSha256(passcode, passcodeLength, block, sizeof(block), u))
  {
    secureZero(block, sizeof(block));
    secureZero(u, sizeof(u));
    secureZero(result, sizeof(result));
    return false;
  }
  memcpy(result, u, sizeof(result));
  for (uint32_t iteration = 1; iteration < PBKDF2_ITERATIONS; iteration++)
  {
    if (!computeHmacSha256(passcode, passcodeLength, u, sizeof(u), u))
    {
      secureZero(block, sizeof(block));
      secureZero(u, sizeof(u));
      secureZero(result, sizeof(result));
      return false;
    }
    for (size_t i = 0; i < sizeof(result); i++)
      result[i] ^= u[i];
    if ((iteration & 0xFF) == 0)
    {
      displayCode();
      yield();
    }
  }
  memcpy(output, result, sizeof(result));
  secureZero(block, sizeof(block));
  secureZero(u, sizeof(u));
  secureZero(result, sizeof(result));
  return true;
}

bool deriveVaultEncryptionKey(const uint8_t *passcode, size_t passcodeLength,
                              const uint8_t salt[16], uint8_t version, uint8_t output[32])
{
  uint8_t baseKey[32];
  if (!deriveVaultKey(passcode, passcodeLength, salt, baseKey))
  {
    secureZero(baseKey, sizeof(baseKey));
    return false;
  }
  if (version == 1)
  {
    memcpy(output, baseKey, sizeof(baseKey));
    secureZero(baseKey, sizeof(baseKey));
    return true;
  }

  static const uint8_t context[] = "NiceTOTP vault AES-256-GCM key v2";
  uint8_t version2Key[sizeof(baseKey)];
  bool okay = computeHmacSha256(baseKey, sizeof(baseKey), context, sizeof(context) - 1, version2Key);
  if (okay && version >= 3)
  {
    static const uint8_t context3[] = "NiceTOTP vault AES-256-GCM settings key v3";
    okay = computeHmacSha256(version2Key, sizeof(version2Key), context3, sizeof(context3) - 1, output);
  }
  else if (okay)
  {
    memcpy(output, version2Key, sizeof(version2Key));
  }
  secureZero(version2Key, sizeof(version2Key));
  secureZero(baseKey, sizeof(baseKey));
  return okay;
}

bool deriveVaultV2KeyFromBase(const uint8_t baseKey[32], uint8_t output[32])
{
  static const uint8_t context[] = "NiceTOTP vault AES-256-GCM key v2";
  return computeHmacSha256(baseKey, 32, context, sizeof(context) - 1, output);
}

bool deriveVaultV3KeyFromV2(const uint8_t version2Key[32], uint8_t output[32])
{
  static const uint8_t context3[] = "NiceTOTP vault AES-256-GCM settings key v3";
  return computeHmacSha256(version2Key, 32, context3, sizeof(context3) - 1, output);
}

void enableApprotect() //(qq5)
{
#if APPROTECT_ENABLED
  if (NRF_UICR->APPROTECT != 0)
  {
    NRF_NVMC->CONFIG = NVMC_CONFIG_WEN_Wen;
    while (NRF_NVMC->READY == 0)
    {
    }
    NRF_UICR->APPROTECT = 0;
    while (NRF_NVMC->READY == 0)
    {
    }
    NRF_NVMC->CONFIG = NVMC_CONFIG_WEN_Ren;
    while (NRF_NVMC->READY == 0)
    {
    }
    NVIC_SystemReset();
  }
#endif
}

void saveCalibration()
{
  if (vaultUnlocked)
    saveKeys();
}

void loadCalibration()
{
  originalSetTime = 0;
  agingOffset = 0;
  calibrationLocked = false;
}

void loadLegacyCalibration()
{
  loadCalibration();
  if (!InternalFS.begin() || !InternalFS.exists(CALIBRATION_FILENAME))
    return;

  File file = InternalFS.open(CALIBRATION_FILENAME, FILE_O_READ);
  if (!file || file.size() != sizeof(originalSetTime) + sizeof(agingOffset) + 1)
  {
    if (file)
      file.close();
    return;
  }

  uint8_t lockedValue;
  file.read((uint8_t *)&originalSetTime, sizeof(originalSetTime));
  file.read((uint8_t *)&agingOffset, sizeof(agingOffset));
  file.read(&lockedValue, sizeof(lockedValue));
  calibrationLocked = lockedValue != 0;
  file.close();
}

int8_t readAgingOffset()
{
  Wire.beginTransmission(DS3231_ADDRESS);
  Wire.write(DS3231_AGING_REGISTER);
  if (Wire.endTransmission() != 0 || Wire.requestFrom(DS3231_ADDRESS, (uint8_t)1) != 1)
    return agingOffset;
  return (int8_t)Wire.read();
}

bool writeAgingOffset(int8_t value)
{
  Wire.beginTransmission(DS3231_ADDRESS);
  Wire.write(DS3231_AGING_REGISTER);
  Wire.write((uint8_t)value);
  return Wire.endTransmission() == 0;
}

/*  https://github.com/ICantMakeThings/Nicenano-NRF52-Supermini-PlatformIO-Support/blob/main/Platformio%20Example%20code/Read%20Batt%20voltage/main.cpp  */
float readBatteryVoltage()
{
  // The volatile keyword is a type qualifier in C/C++ that tells the compiler a variable's value might change in ways that the compiler cannot detect from the code alone.
  // Essentially, it says: "Don't optimize access to this variable because its value might change unexpectedly."
  volatile uint32_t raw_value = 0;
  // Configure SAADC
  NRF_SAADC->ENABLE = 1;
  NRF_SAADC->RESOLUTION = SAADC_RESOLUTION_VAL_12bit;

  NRF_SAADC->CH[0].CONFIG =
      (SAADC_CH_CONFIG_GAIN_Gain1_4 << SAADC_CH_CONFIG_GAIN_Pos) |
      (SAADC_CH_CONFIG_MODE_SE << SAADC_CH_CONFIG_MODE_Pos) |
      (SAADC_CH_CONFIG_REFSEL_Internal << SAADC_CH_CONFIG_REFSEL_Pos);

  NRF_SAADC->CH[0].PSELP = SAADC_CH_PSELP_PSELP_VDDHDIV5;
  NRF_SAADC->CH[0].PSELN = SAADC_CH_PSELN_PSELN_NC;

  // Sample
  NRF_SAADC->RESULT.PTR = (uint32_t)&raw_value;
  NRF_SAADC->RESULT.MAXCNT = 1;
  NRF_SAADC->TASKS_START = 1;
  while (!NRF_SAADC->EVENTS_STARTED)
    ;
  NRF_SAADC->EVENTS_STARTED = 0;
  NRF_SAADC->TASKS_SAMPLE = 1;
  while (!NRF_SAADC->EVENTS_END)
    ;
  NRF_SAADC->EVENTS_END = 0;
  NRF_SAADC->TASKS_STOP = 1;
  while (!NRF_SAADC->EVENTS_STOPPED)
    ;
  NRF_SAADC->EVENTS_STOPPED = 0;
  NRF_SAADC->ENABLE = 0;

  // Force explicit double-precision calculations
  double raw_double = (double)raw_value;
  double step1 = raw_double * 2.4;
  double step2 = step1 / 4095.0;
  double vddh = 5.0 * step2;

  return (float)vddh;
}

// Batt status

void drawBatteryIcon(float voltage)
{
  const int iconX = SCREEN_WIDTH - 18;
  const int iconY = 0;
  const int iconWidth = 16;
  const int iconHeight = 6;
  const int terminalWidth = 2;

  display.drawRect(iconX, iconY, iconWidth, iconHeight, SSD1306_WHITE);
  display.fillRect(iconX + iconWidth, iconY + 2, terminalWidth, iconHeight - 4, SSD1306_WHITE);

  float minV = 3.0;
  float maxV = 4.2;
  bool isCharging = (voltage >= 4.3);

  if (isCharging)
  {
    const int fillMax = iconWidth - 4;
    int animPhase = (millis() / 150) % (fillMax + 1);

    display.fillRect(iconX + 2, iconY + 2, animPhase, iconHeight - 4, SSD1306_WHITE);
  }
  else
  {
    int fillWidth = (int)((voltage - minV) / (maxV - minV) * (iconWidth - 4));
    if (fillWidth < 0)
      fillWidth = 0;
    if (fillWidth > iconWidth - 4)
      fillWidth = iconWidth - 4;

    if (fillWidth > 0)
    {
      display.fillRect(iconX + 2, iconY + 2, fillWidth, iconHeight - 4, SSD1306_WHITE);
    }
  }
}

void drawTopStatus(bool showBack, bool backSelected)
{
  if (showBack)
  {
    if (backSelected)
    {
      display.fillRoundRect(0, 0, 10, 7, 2, SSD1306_WHITE);
      display.drawLine(6, 0, 3, 3, SSD1306_BLACK);
      display.drawLine(3, 3, 6, 6, SSD1306_BLACK);
      display.drawFastHLine(3, 3, 5, SSD1306_BLACK);
    }
    else
    {
      display.drawLine(6, 0, 3, 3, SSD1306_WHITE);
      display.drawLine(3, 3, 6, 6, SSD1306_WHITE);
      display.drawFastHLine(3, 3, 5, SSD1306_WHITE);
    }
  }

  uint32_t nowMillis = millis();
  if (!clockTextReady || nowMillis - clockTextUpdatedAt >= 1000)
  {
    int64_t localEpoch = (int64_t)rtc.now().unixtime() + (int64_t)utcOffsetMinutes * 60;
    if (localEpoch < 0)
      localEpoch = 0;
    DateTime localTime((uint32_t)localEpoch);
    if (clock24Hour)
    {
      snprintf(cachedClockText, sizeof(cachedClockText), "%02u:%02u",
               (unsigned int)localTime.hour(), (unsigned int)localTime.minute());
    }
    else
    {
      uint8_t hour = localTime.hour() % 12;
      if (hour == 0)
        hour = 12;
      snprintf(cachedClockText, sizeof(cachedClockText), "%u:%02u%c", (unsigned int)hour,
               (unsigned int)localTime.minute(), localTime.hour() < 12 ? 'a' : 'p');
    }
    clockTextUpdatedAt = nowMillis;
    clockTextReady = true;
  }
  display.setFont(nullptr);
  display.setTextSize(1);
  display.setTextColor(SSD1306_WHITE);
  int16_t textX, textY;
  uint16_t textWidth, textHeight;
  display.getTextBounds(cachedClockText, 0, 0, &textX, &textY, &textWidth, &textHeight);
  display.setCursor(SCREEN_WIDTH - 22 - textWidth, 0);
  display.print(cachedClockText);
  drawBatteryIcon(readBatteryVoltage());
}

// Files

const uint8_t VAULT_MAGIC_V1[5] = {'N', 'T', 'V', '1', 1};
const uint8_t VAULT_MAGIC_V2[5] = {'N', 'T', 'V', '2', 2};
const uint8_t VAULT_MAGIC_V3[5] = {'N', 'T', 'V', '3', 3};
const size_t VAULT_HEADER_SIZE = 33;
const size_t VAULT_TAG_SIZE = 16;
const uint32_t LOCKOUT_DELAYS_MS[10] = {
    0, 0, 30000UL, 60000UL, 300000UL,
    600000UL, 1800000UL, 21600000UL, 86400000UL, 0};

bool saveAttemptState()
{
  if (!InternalFS.begin())
    return false;
  uint8_t record[5] = {'A', 'T', 1, failedAttempts, 0};
  record[4] = (uint8_t)(record[0] ^ record[1] ^ record[2] ^ record[3] ^ 0xA5);
  if (InternalFS.exists("/attempts.tmp"))
    InternalFS.remove("/attempts.tmp");
  File file = InternalFS.open("/attempts.tmp", FILE_O_WRITE);
  if (!file)
    return false;
  bool written = file.write(record, sizeof(record)) == sizeof(record);
  file.flush();
  file.close();
  if (!written)
  {
    InternalFS.remove("/attempts.tmp");
    return false;
  }
  if (InternalFS.exists(ATTEMPTS_FILENAME) && !InternalFS.remove(ATTEMPTS_FILENAME))
    return false;
  return InternalFS.rename("/attempts.tmp", ATTEMPTS_FILENAME);
}

void loadAttemptState()
{
  failedAttempts = 0;
  if (!InternalFS.begin())
    return;
  if (!InternalFS.exists(ATTEMPTS_FILENAME) && InternalFS.exists("/attempts.tmp"))
    InternalFS.rename("/attempts.tmp", ATTEMPTS_FILENAME);
  else if (InternalFS.exists(ATTEMPTS_FILENAME) && InternalFS.exists("/attempts.tmp"))
    InternalFS.remove("/attempts.tmp");
  if (!InternalFS.exists(ATTEMPTS_FILENAME))
    return;

  File file = InternalFS.open(ATTEMPTS_FILENAME, FILE_O_READ);
  if (!file)
    return;
  uint8_t record[5] = {0};
  bool valid = file.size() == sizeof(record) && file.read(record, sizeof(record)) == sizeof(record);
  file.close();
  if (valid && record[0] == 'A' && record[1] == 'T' && record[2] == 1 &&
      record[4] == (uint8_t)(record[0] ^ record[1] ^ record[2] ^ record[3] ^ 0xA5) &&
      record[3] <= MAX_FAILED_ATTEMPTS)
    failedAttempts = record[3];
}

bool saveClockDisplaySettings()
{
  if (!InternalFS.begin())
    return false;
  uint8_t record[6] = {'C', 'L', (uint8_t)utcOffsetMinutes,
                       (uint8_t)((uint16_t)utcOffsetMinutes >> 8),
                       (uint8_t)(clock24Hour ? 1 : 0), 0};
  record[5] = (uint8_t)(record[0] ^ record[1] ^ record[2] ^ record[3] ^ record[4] ^ 0xA5);
  if (InternalFS.exists("/clock.tmp"))
    InternalFS.remove("/clock.tmp");
  File file = InternalFS.open("/clock.tmp", FILE_O_WRITE);
  if (!file)
    return false;
  bool written = file.write(record, sizeof(record)) == sizeof(record);
  file.flush();
  file.close();
  if (!written)
  {
    InternalFS.remove("/clock.tmp");
    return false;
  }
  if (InternalFS.exists(CLOCK_DISPLAY_FILENAME) && !InternalFS.remove(CLOCK_DISPLAY_FILENAME))
    return false;
  return InternalFS.rename("/clock.tmp", CLOCK_DISPLAY_FILENAME);
}

void loadClockDisplaySettings()
{
  utcOffsetMinutes = 0;
  clock24Hour = true;
  clockTextReady = false;
  if (!InternalFS.begin())
    return;

  if (InternalFS.exists("/clock.tmp"))
  {
    File temporary = InternalFS.open("/clock.tmp", FILE_O_READ);
    uint8_t record[6] = {0};
    bool valid = temporary && temporary.size() == sizeof(record) &&
                 temporary.read(record, sizeof(record)) == sizeof(record) &&
                 record[0] == 'C' && record[1] == 'L' &&
                 record[5] == (uint8_t)(record[0] ^ record[1] ^ record[2] ^ record[3] ^ record[4] ^ 0xA5);
    if (temporary)
      temporary.close();
    if (valid)
    {
      if (InternalFS.exists(CLOCK_DISPLAY_FILENAME))
        InternalFS.remove(CLOCK_DISPLAY_FILENAME);
      InternalFS.rename("/clock.tmp", CLOCK_DISPLAY_FILENAME);
    }
    else
      InternalFS.remove("/clock.tmp");
    secureZero(record, sizeof(record));
  }

  if (!InternalFS.exists(CLOCK_DISPLAY_FILENAME))
    return;
  File file = InternalFS.open(CLOCK_DISPLAY_FILENAME, FILE_O_READ);
  if (!file)
    return;
  uint8_t record[6] = {0};
  bool valid = file.size() == sizeof(record) && file.read(record, sizeof(record)) == sizeof(record) &&
               record[0] == 'C' && record[1] == 'L' && record[4] <= 1 &&
               record[5] == (uint8_t)(record[0] ^ record[1] ^ record[2] ^ record[3] ^ record[4] ^ 0xA5);
  file.close();
  if (valid)
  {
    uint16_t rawOffset = (uint16_t)record[2] | ((uint16_t)record[3] << 8);
    int16_t offset = (int16_t)rawOffset;
    if (offset >= -840 && offset <= 840 && offset % 30 == 0)
    {
      utcOffsetMinutes = offset;
      clock24Hour = record[4] != 0;
      clockTextReady = false;
    }
  }
  secureZero(record, sizeof(record));
}

void recoverVaultFile()
{
  if (!InternalFS.begin())
    return;
  if (!InternalFS.exists(VAULT_FILENAME))
  {
    bool completeTemp = vaultFileIsComplete("/vault.tmp");
    if (completeTemp)
      InternalFS.rename("/vault.tmp", VAULT_FILENAME);
    if (!InternalFS.exists(VAULT_FILENAME) && InternalFS.exists("/vault.bak"))
      InternalFS.rename("/vault.bak", VAULT_FILENAME);
    else if (!completeTemp && !InternalFS.exists("/vault.bak") && InternalFS.exists("/vault.tmp"))
      InternalFS.remove("/vault.tmp");
  }
  vaultPresent = InternalFS.exists(VAULT_FILENAME);
  if (vaultPresent)
  {
    if (InternalFS.exists(PIN_FILENAME))
      InternalFS.remove(PIN_FILENAME);
    if (InternalFS.exists(KEYS_FILENAME))
      InternalFS.remove(KEYS_FILENAME);
    if (InternalFS.exists(CALIBRATION_FILENAME))
      InternalFS.remove(CALIBRATION_FILENAME);
  }
}
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
void loop()
{
  handleButtons();
  if (!locked && usbExposed)
    processSerialInput();

  /*
  // Took part from: https://github.com/adafruit/Adafruit_nRF52_Arduino/blob/master/libraries/Bluefruit52Lib/examples/Peripheral/bleuart/bleuart.ino
  while (Serial.available())
  {
    // Delay to wait for enough input, since we have a limited transmission buffer
    delay(2);

    uint8_t buf[64];
    int count = Serial.readBytes(buf, sizeof(buf));
    bleuart.write(buf, count);
  }

  // Forward from BLEUART to HW Serial
  while (bleuart.available())
  {
    uint8_t ch;
    ch = (uint8_t)bleuart.read();
    Serial.write(ch);
  }
*/
  displayCode();

  bool configuratorConnected =
      (!locked &&
        usbExposed &&
       (millis() - lastConfiguratorHeartbeat) <= CONFIGURATOR_TIMEOUT);

  if ((millis() - lastActivityTime) > INACTIVITY_TIMEOUT && !configuratorConnected)
  {
    enterUltraSleep();
  }

  delay(50);
}

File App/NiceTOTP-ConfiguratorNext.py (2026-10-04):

import base64
import json
import os
import queue
import re
import shutil
import sys
import tempfile
import threading
import time
import urllib.parse
import urllib.request
from pathlib import Path
from typing import Protocol

try:
    import serial
    from serial.tools import list_ports
except ImportError:
    serial = None
    list_ports = None
from PySide6.QtCore import QObject, Property, QProcess, QSettings, QStorageInfo, QThread, QTimer, QUrl, Signal, Slot
from PySide6.QtGui import QGuiApplication
from PySide6.QtQml import QQmlApplicationEngine


class DeviceTransport(Protocol):
    @property
    def connected(self): ...

    def find_device(self): ...

    def connect(self, device): ...

    def send(self, command): ...

    def read_lines(self): ...

    def close(self): ...


class UsbSerialTransport:
    """USB serial adapter."""

    def __init__(self):
        self._serial = None
        self._buffer = bytearray()
        self._device_id = None

    def find_device(self):
        if list_ports is None:
            return None
        ports = list(list_ports.comports())
        identified = []
        usb_serial = []

        for port in ports:
            identity = " ".join(
                str(value or "")
                for value in (port.product, port.manufacturer, port.description)
            ).lower()
            if "nicetotp" in identity or "icantmakethings" in identity:
                identified.append(port.device)
                continue

            device = port.device.lower()
            hardware_id = str(port.hwid or "").lower()
            is_usb_serial = (
                port.vid is not None
                or "usb" in hardware_id
                or device.startswith(("/dev/ttyacm", "/dev/cu.usb", "/dev/tty.usb"))
            )
            if is_usb_serial:
                usb_serial.append(port.device)

        if len(identified) == 1:
            return identified[0]
        if not identified and len(usb_serial) == 1:
            return usb_serial[0]
        return None

    @property
    def connected(self):
        return self._serial is not None and self._serial.is_open

    @property
    def device_id(self):
        return self._device_id

    def connect(self, port):
        if serial is None:
            raise OSError("USB serial transport is unavailable")
        self.close()
        self._serial = serial.Serial(port, baudrate=115200, timeout=0, write_timeout=0.5)
        self._device_id = port
        self._buffer.clear()

    def send(self, command):
        if not self.connected:
            return False
        self._serial.write((command + "\n").encode("utf-8"))
        return True

    def read_lines(self):
        if not self.connected:
            return []
        waiting = self._serial.in_waiting
        if waiting:
            self._buffer.extend(self._serial.read(waiting))
        lines = []
        while b"\n" in self._buffer:
            line, _, rest = self._buffer.partition(b"\n")
            self._buffer = bytearray(rest)
            decoded = line.decode("utf-8", errors="replace").strip("\r \t")
            if decoded:
                lines.append(decoded)
        return lines

    def close(self):
        if self._serial is not None:
            try:
                self._serial.close()
            except OSError:
                pass
        self._serial = None
        self._device_id = None
        self._buffer.clear()


class Uf2UpdateWorker(QThread):
    completed = Signal(bool, str)

    def __init__(self, firmware_path):
        super().__init__()
        self._firmware_path = Path(firmware_path)

    def run(self):
        deadline = time.monotonic() + 60
        while time.monotonic() < deadline and not self.isInterruptionRequested():
            for volume in QStorageInfo.mountedVolumes():
                if not volume.isValid() or not volume.isReady():
                    continue
                mount = Path(volume.rootPath())
                if not (mount / "INFO_UF2.TXT").is_file():
                    continue
                try:
                    shutil.copy2(self._firmware_path, mount / self._firmware_path.name)
                    self.completed.emit(True, f"Firmware copied to {mount}.")
                    return
                except OSError as error:
                    self.completed.emit(False, f"Could not copy firmware: {error}")
                    return
            time.sleep(0.5)
        message = "UF2 update cancelled." if self.isInterruptionRequested() else "UF2 boot drive was not detected within 60 seconds."
        self.completed.emit(False, message)


class ReleaseListWorker(QThread):
    completed = Signal("QVariantList", str)

    def run(self):
        url = "https://api.github.com/repos/ICantMakeThings/NiceTOTP/releases?per_page=100"
        assets = []
        try:
            while url:
                request = urllib.request.Request(
                    url,
                    headers={"Accept": "application/vnd.github+json", "User-Agent": "NiceTOTP-Configurator-Next"},
                )
                with urllib.request.urlopen(request, timeout=20) as response:
                    releases = json.loads(response.read().decode("utf-8"))
                    next_link = response.headers.get("Link", "")
                for release in releases:
                    for asset in release.get("assets", []):
                        if asset.get("name", "").lower().endswith(".uf2"):
                            assets.append({
                                "name": f"{release.get('tag_name', 'Release')} · {asset['name']}",
                                "tag": release.get("tag_name", ""),
                                "asset": asset["name"],
                                "downloadUrl": asset["browser_download_url"],
                            })
                match = re.search(r'<([^>]+)>;\s*rel="next"', next_link)
                url = match.group(1) if match else ""
            self.completed.emit(assets, "" if assets else "No UF2 assets found in GitHub releases.")
        except Exception as error:
            self.completed.emit([], f"Could not load GitHub releases: {error}")
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

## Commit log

2025-07-10 swapped buttons
2026-01-21 added dfu mode by holding both buttons at once for 10s or more
2026-09-09 added uf2 tool, fixed sleep when configurating, added script to build uf2 automatically
    [NiceTOTP-Configurator.py, main.cpp]
2026-10-05 feat: PCB to connect everything together
    [NiceTOTP.kicad_pcb, NiceTOTP.kicad_sch]
